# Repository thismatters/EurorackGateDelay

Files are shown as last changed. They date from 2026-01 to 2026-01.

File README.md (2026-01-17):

# Gate Delay

The circuit here is based on the [Yusynth Gate Delay](https://yusynth.net/Modular/EN/GATEDELAY/index.html) with minor tweaks to make it more Eurorack friendly. The changes I've made are thus:
* Selected resistors appropriate for +/-12V rails,
* Added polarity protection so that a backward power header doesn't fry anything (twin series schotty diodes: BAT54SL),
* Full surface mount design,
* Preseve gate duration in the delay.

The maximum delay is approximately 250ms, although by changing some resistor or capacitor values you may be able to extend that by quite a degree. I kept the delay to a moderate value to prevent distortion in delay duration. The main enhancement here over the original circuit is that the duration of the output gate mimicks the duration of the input gate. The output duration can be slightly longer than the input when the delay is set to high values.

The Yusynth page is a treasure trove of information about this circuit that I am too amateur to claim as my own; please read that outstanding page before using this circuit. The page provides many details and other implementations of this circuit that you may find suitable.

The KiCAD project here uses the library/footprints [found in my companion repo](https://github.com/thismatters/EurorackKiCAD).

## Width

12hp on an Intellijel 1U rack.

## Inputs

Jack for Gate

Potentiometer for delay duration

## Outputs

LED to indicate gate output

Jacks:
- Gate
- Slew (Logarithmic)

## Vendors

There are part numbers in the [BOM](gate-delay.csv) for many of the parts (not for basic passives though) at the following vendors:

* [Mouser](https://www.mouser.com): Needs no introduction. Get your ICs from here (or [digikey](https://www.digikey.com)).
* [Tayda Electronics](https://www.taydaelectronics.com/): Good supplier for passive components; audio jacks, and potentiometers. Their audio jacks are slightly smaller than the thonkiconn from thonk.
* [Love My Switches](https://lovemyswitches.com/): Has [really good knobs](https://lovemyswitches.com/anodized-aluminum-knob-the-lo-fi-1-4-smooth-shaft-12-5mm-od/) to go on those potentiometers!
* [OSHPark](https://oshpark.com/): Fast and (relatively) cheap PCB manufacturer. Prototype run pending.

## Changelog

### V1

* Updated resistor value for R8 to 22K

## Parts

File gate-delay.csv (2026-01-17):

# | Reference | Qty | Value | Footprint | DNP | Vendor | PartNum
1 | C1, C2 | 2 | 22u 50V | Capacitor_THT:CP_Radial_D5.0mm_P2.50mm
2 | C3 | 1 | 1u box | Capacitor_THT:C_Rect_L7.2mm_W5.5mm_P5.00mm_FKS2_FKP2_MKS2_MKP2
3 | C4 | 1 | 100n | Capacitor_SMD:C_0805_2012Metric
4 | D1, D2 | 2 | BAT54S | Package_TO_SOT_SMD:SOT-23 |  | Mouser | 863-BAT54SLT1G
5 | D3, D4 | 2 | 1N4148 | Diode_SMD:D_SOD-323_HandSoldering
6 | D5 | 1 | LED_GREEN | LED_THT:LED_D3.0mm
7 | J1 | 1 | Conn_02x05_Odd_Even | Eurorack:PinHeader_2x05_P2.54mm_Vertical |  | Tayda | A-2939
8 | J2 | 1 | gate_in | Eurorack:AudioJack2_Tayda_A-2566 |  | Tayda | A-2566
9 | J3 | 1 | gate_out | Eurorack:AudioJack2_Tayda_A-2566 |  | Tayda | A-2566
10 | J4 | 1 | slew_out | Eurorack:AudioJack2_Tayda_A-2566 |  | Tayda | A-2566
11 | Q1 | 1 | BCM847 | Package_SO:TSOP-6_1.65x3.05mm_P0.95mm |  | Mouser | 771-BCM847DS135
12 | Q2 | 1 | BSS84 | Package_TO_SOT_SMD:SOT-23 |  | Mouser | 512-BSS84
13 | Q3 | 1 | MMBF170 | Package_TO_SOT_SMD:SOT-23 |  | Mouser | 863-MMBF170LT1G
14 | R1, R2 | 2 | 10 | Resistor_SMD:R_0805_2012Metric
15 | R3, R6, R7, R10, R12, R13, R14 | 7 | 1K | Resistor_SMD:R_0805_2012Metric
16 | R4, R5, R8, R9 | 4 | 22K | Resistor_SMD:R_0805_2012Metric
17 | R11 | 1 | 10K | Resistor_SMD:R_0805_2012Metric
18 | RV1 | 1 | A1M | Eurorack:Potentiometer_RV16AF-41-15R1
19 | U1 | 1 | TL072 | Package_SO:SOIC-8_3.9x4.9mm_P1.27mm |  | Mouser | 771-BCM847DS135

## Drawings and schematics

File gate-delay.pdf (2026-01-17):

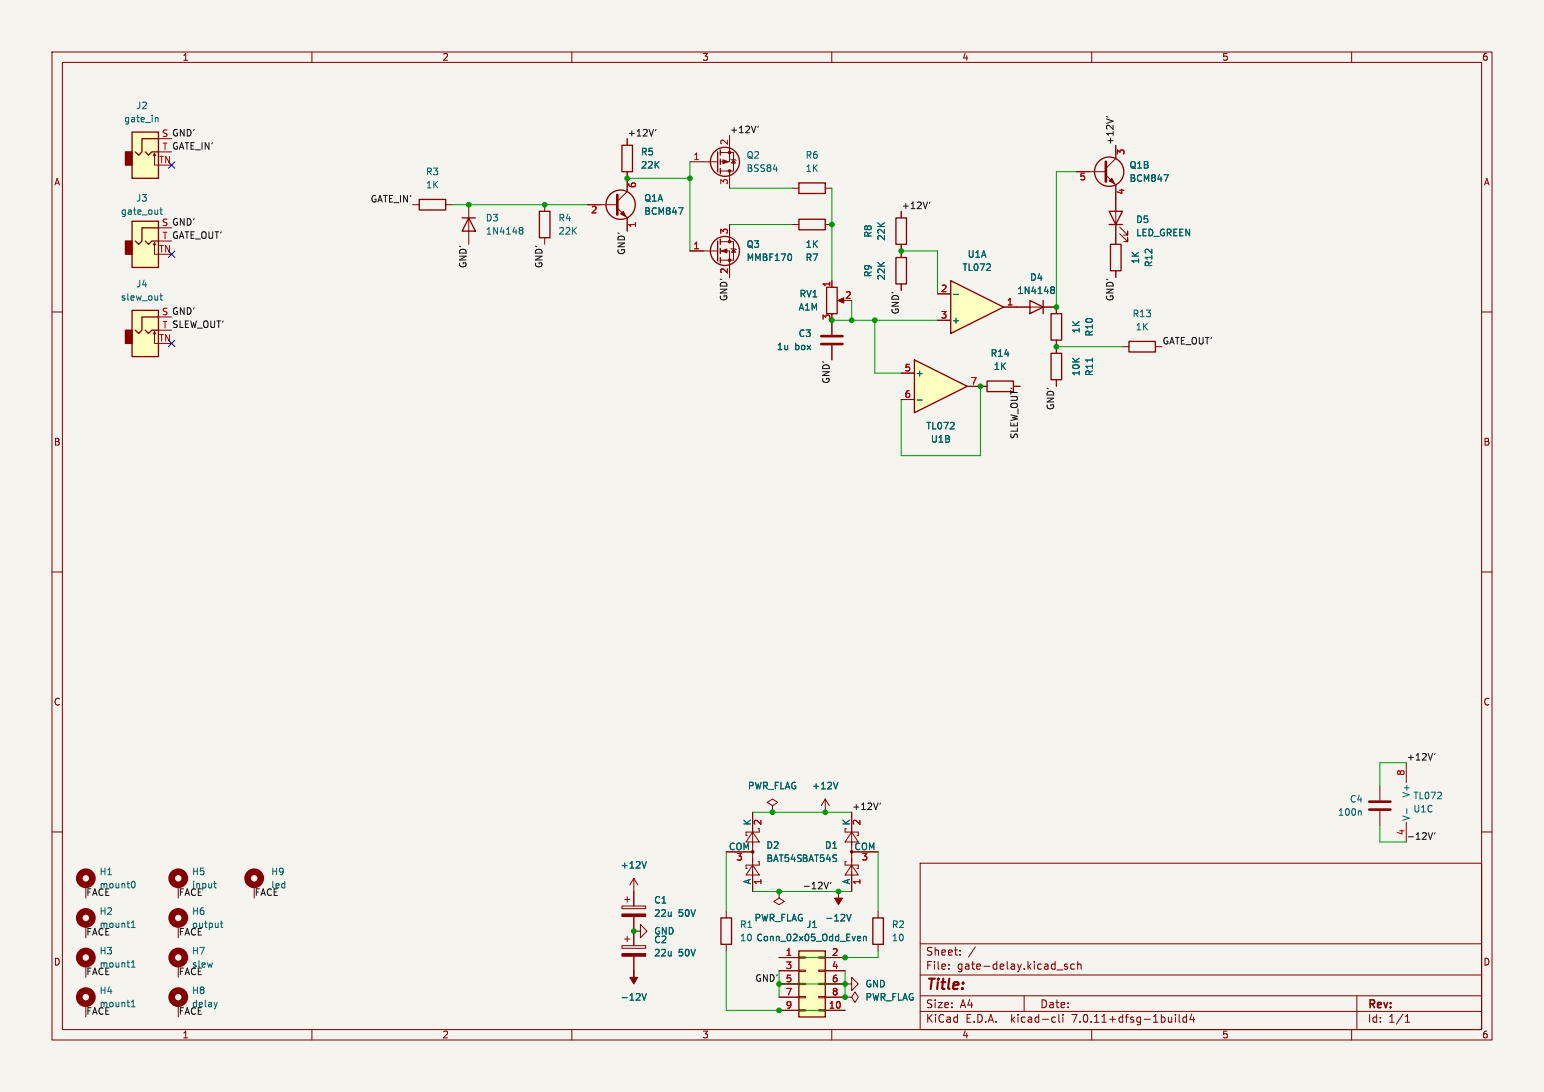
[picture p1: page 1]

Id: 1/1 Title: File: gate-delay.kicad_sch

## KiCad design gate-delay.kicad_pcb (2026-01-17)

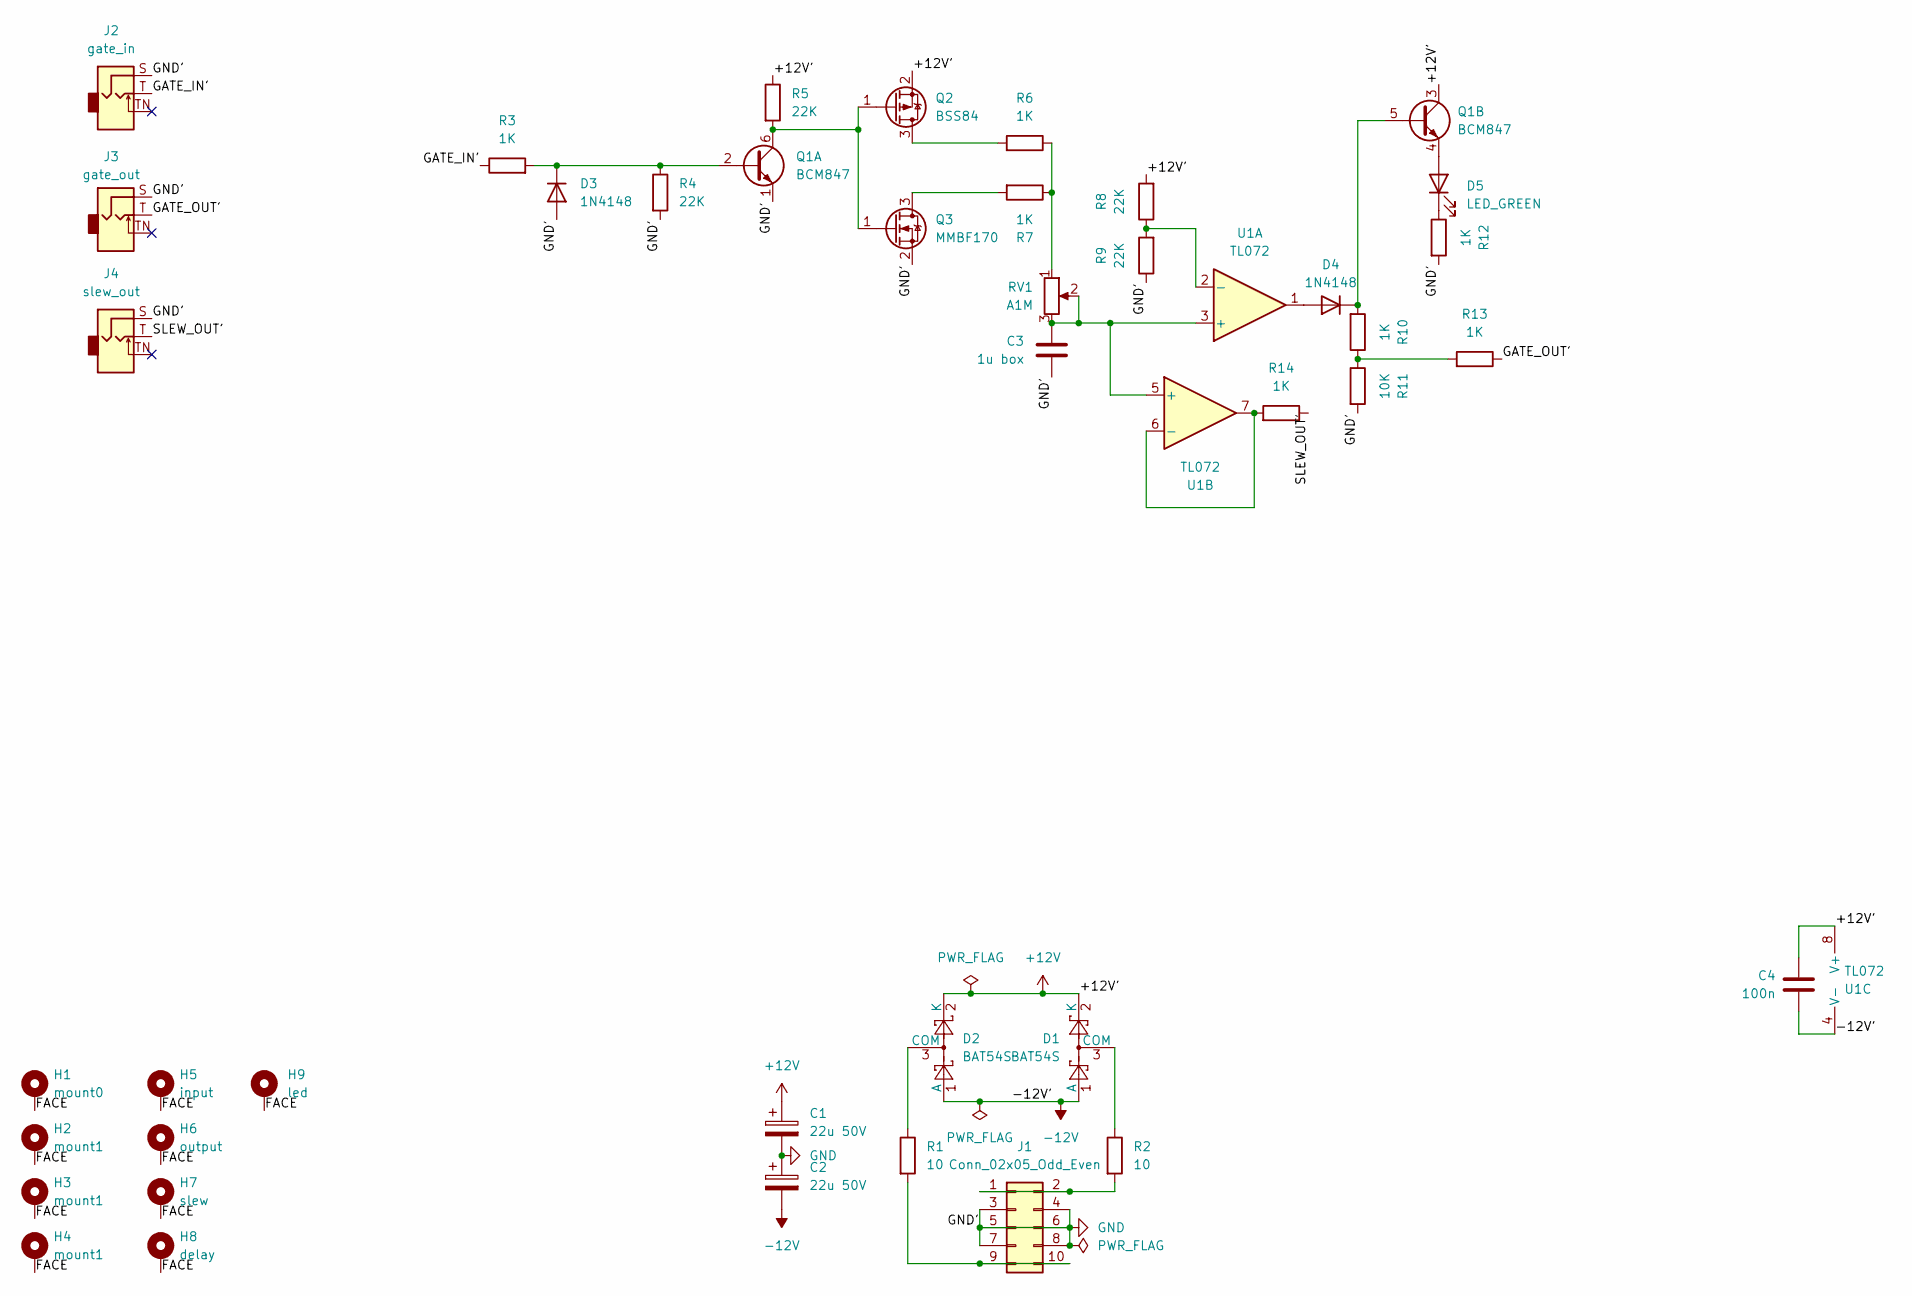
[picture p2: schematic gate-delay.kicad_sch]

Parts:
C1, C2: 22u 50V; CP_Radial_D5.0mm_P2.50mm
C3: 1u box; C_Rect_L7.2mm_W5.5mm_P5.00mm_FKS2_FKP2_MKS2_MKP2
C4: 100n; C_0805_2012Metric
D1, D2: BAT54S; SOT-23; PartNum 863-BAT54SLT1G
D3, D4: 1N4148; D_SOD-323_HandSoldering
D5: LED_GREEN; LED_D3.0mm
H1: mount0; Mech-MountingHole
H2, H3, H4: mount1; Mech-MountingHole
H5: input; Mech-AudioJack-Hole-Input-Gate
H6: output; Mech-AudioJack-Hole-Output-Gate
H7: slew; Mech-AudioJack-Hole-Output-CV
H8: delay; Mech-Potentiometer-Hole_level_90deg
H9: led; Mech-LED-Hole-3mm-Bezel
J1: Conn_02x05_Odd_Even; PinHeader_2x05_P2.54mm_Vertical; PartNum A-2939
J2: gate_in; AudioJack2_Tayda_A-2566; PartNum A-2566
J3: gate_out; AudioJack2_Tayda_A-2566; PartNum A-2566
J4: slew_out; AudioJack2_Tayda_A-2566; PartNum A-2566
Q1: BCM847; TSOP-6_1.65x3.05mm_P0.95mm; PartNum 771-BCM847DS135
Q2: BSS84; SOT-23; PartNum 512-BSS84
Q3: MMBF170; SOT-23; PartNum 863-MMBF170LT1G
R1, R2: 10; R_0805_2012Metric
R3, R6, R7, R10, R12, R13, R14: 1K; R_0805_2012Metric
R4, R5, R8, R9: 22K; R_0805_2012Metric
R11: 10K; R_0805_2012Metric
RV1: A1M; Potentiometer_RV16AF-41-15R1
U1: TL072; SOIC-8_3.9x4.9mm_P1.27mm; PartNum 771-BCM847DS135

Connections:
+12V: C1.1, C4.1, D1.2 (K), D2.2 (K), Q1.3 (C2), Q2.2 (S), R5.1, R8.2, U1.8 (V+)
-12V: C2.2, C4.2, D1.1 (A), D2.1 (A), U1.4 (V-)
/FACE: H1.1, H2.1, H3.1, H4.1, H5.1, H6.1, H7.1, H8.1, H9.1
/GATE_IN': J2.T, R3.1
/GATE_OUT': J3.T, R13.1
/SLEW_OUT': J4.T, R14.1
GND: C1.2, C2.1, C3.2, D3.2 (A), J1.3, J1.4, J1.5, J1.6, J1.7, J1.8, J2.S, J3.S, J4.S, Q1.1 (E1), Q3.2 (S), R4.2, R9.1, R11.2, R12.2
unnamed: D1.3 (COM), R2.1
unnamed: D2.3 (COM), R1.1
unnamed: D3.1 (K), Q1.2 (B1), R3.2, R4.1
unnamed: D4.2 (A), U1.1
unnamed: D4.1 (K), Q1.5 (B2), R10.2
unnamed: D5.2 (A), Q1.4 (E2)
unnamed: D5.1 (K), R12.1
unnamed: J1.1, J1.2, R2.2
unnamed: J1.9, J1.10, R1.2
unnamed: Q1.6 (C1), Q2.1 (G), Q3.1 (G), R5.2
unnamed: Q2.3 (D), R6.2
unnamed: Q3.3 (D), R7.2
unnamed: R6.1, R7.1, RV1.1
unnamed: R10.1, R11.1, R13.2
unnamed: C3.1, RV1.2, RV1.3, U1.3 (+), U1.5 (+)
unnamed: R8.1, R9.2, U1.2 (-)
unnamed: R14.2, U1.6 (-), U1.7

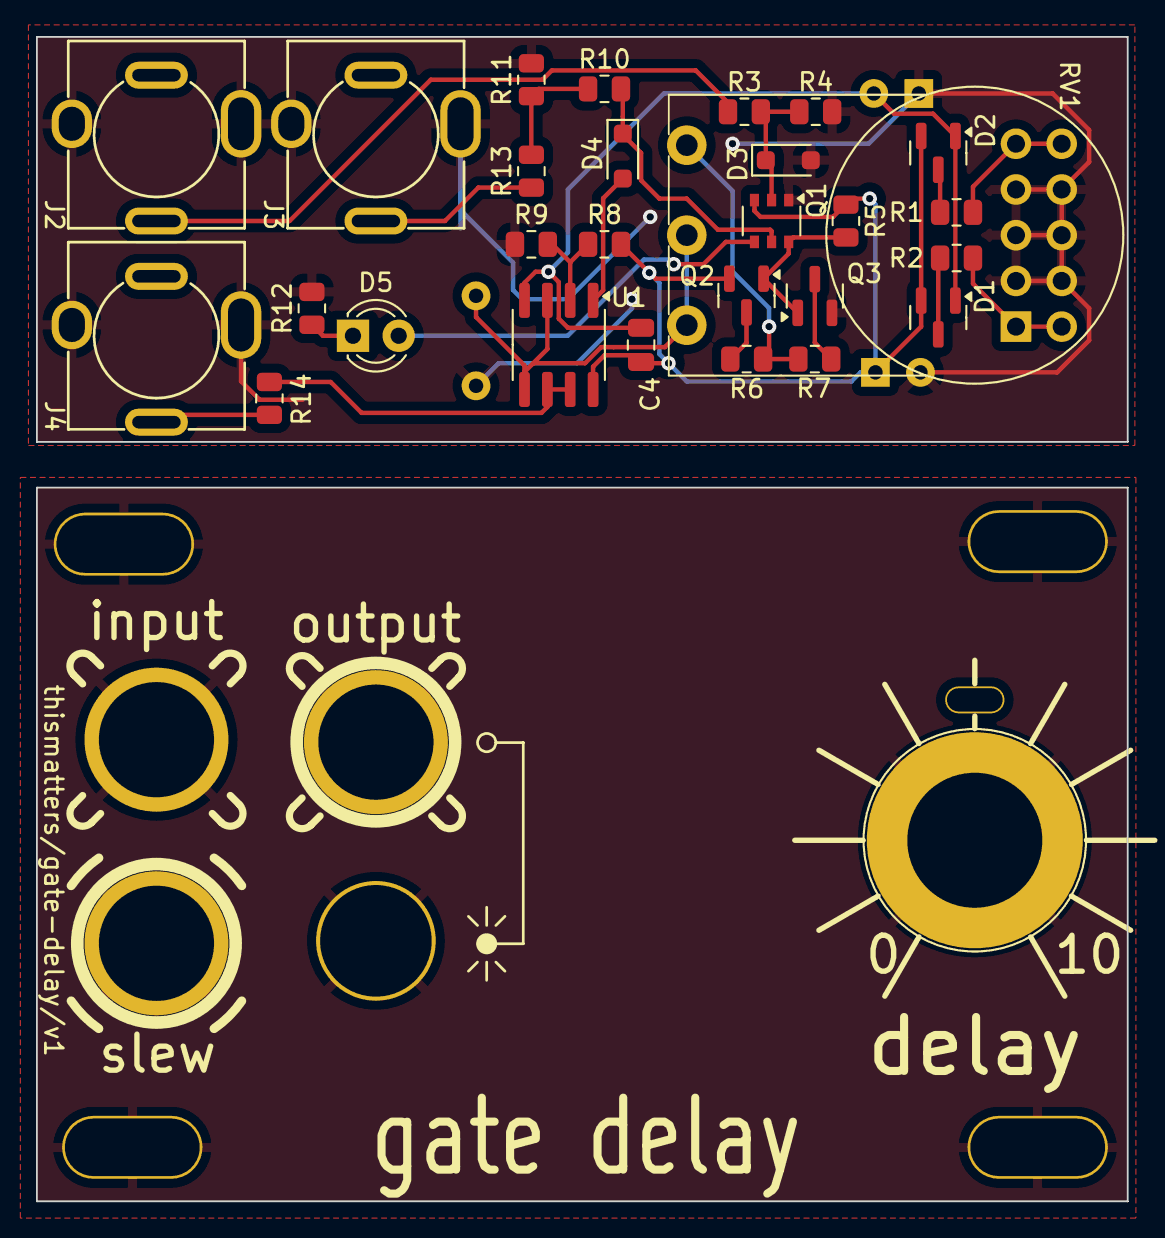
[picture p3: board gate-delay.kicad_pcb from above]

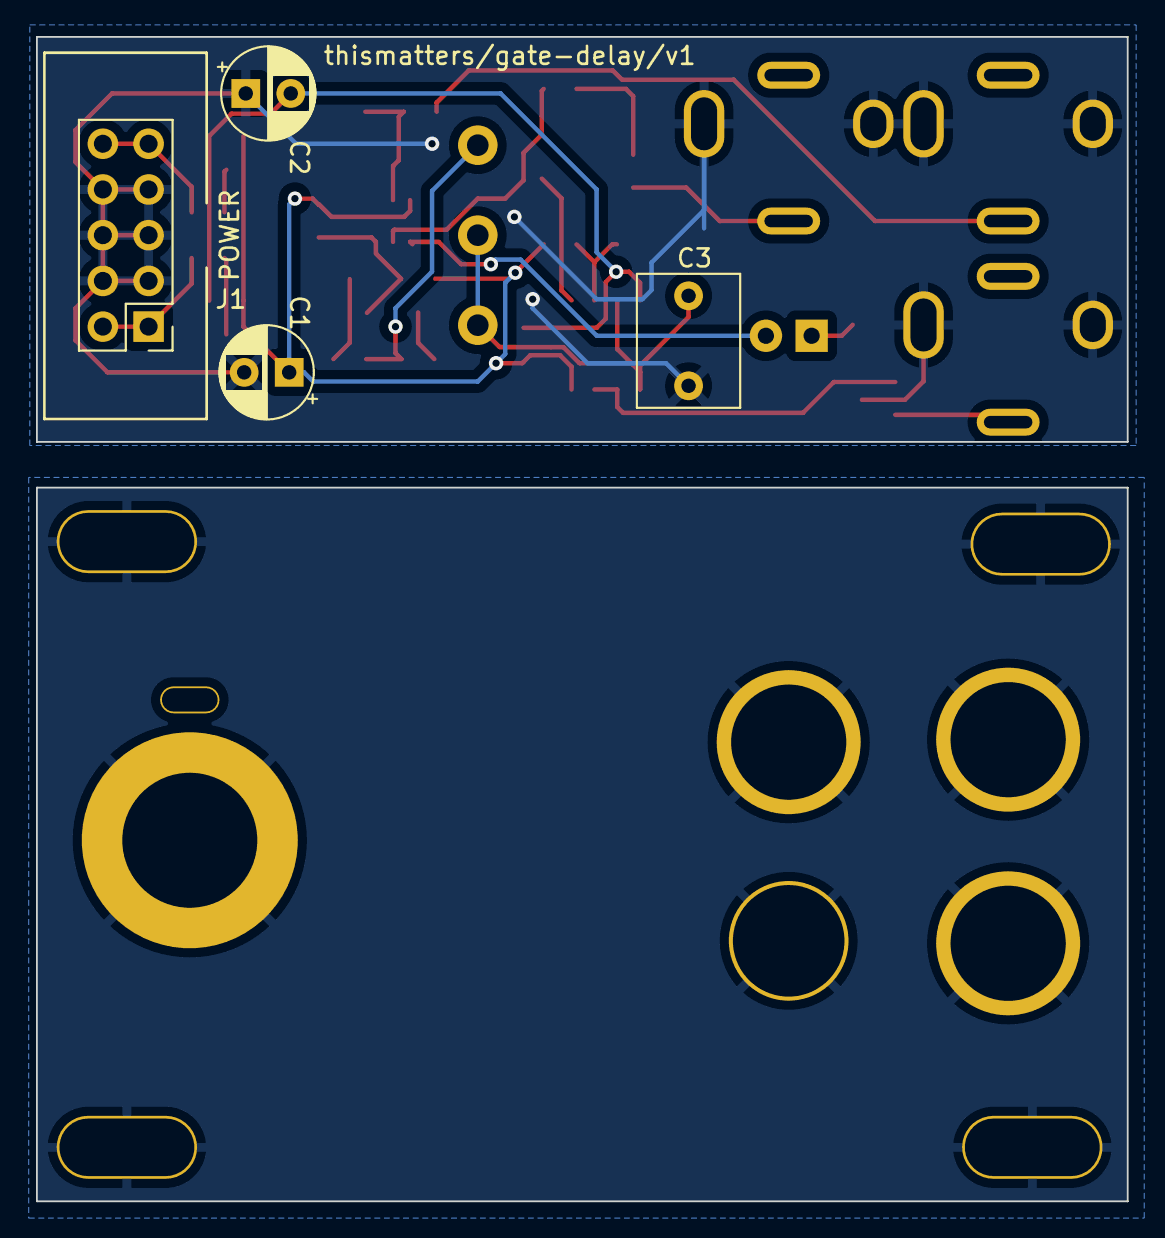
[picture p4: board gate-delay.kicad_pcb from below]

Board: 2 copper layers, 60.6 x 64.7 mm, 41 parts (4 on the bottom side), 24 nets.

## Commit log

2025-01-05 fix: try to maintain gate duration
    [gate-delay.kicad_sch]
2025-04-05 feat: v0 pcb layed out
    [gate-delay.csv, gate-delay.kicad_pcb, gate-delay.kicad_sch]
2026-01-17 v1 ready (uses the v0 board)
    [gate-delay.csv, gate-delay.kicad_pcb, gate-delay.kicad_sch]
